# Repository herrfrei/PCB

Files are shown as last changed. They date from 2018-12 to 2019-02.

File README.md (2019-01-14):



Dieses Werk ist lizenziert unter einer [Creative Commons Namensnennung - Nicht-kommerziell - Weitergabe unter gleichen Bedingungen 4.0 International Lizenz](http://creativecommons.org/licenses/by-nc-sa/4.0/).

Bei Nutzung der Platinen freue ich mich über Feedback und kleine Aufmerksamkeiten aus meiner [Amazon Wunschliste](https://www.amazon.de/gp/registry/wishlist/3NNUQIQO20AAP/ref=nav_wishlist_lists_1).

# PCB
## HB-RF-USB
Eine Platine um die Homematic Funkmodule HM-MOD-RPI-PCB und RF-RPI-MOD per USB anschließen zu können.
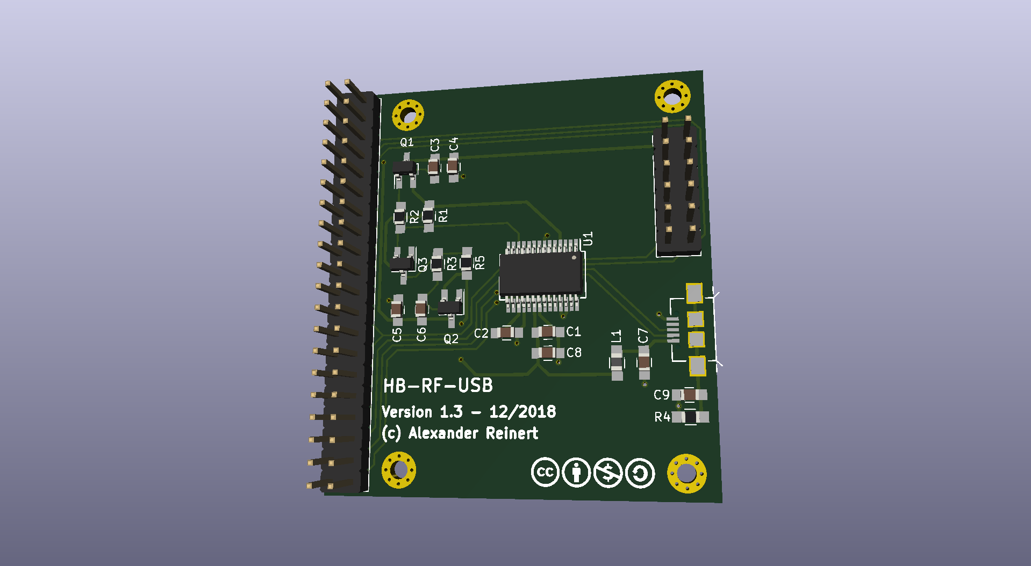
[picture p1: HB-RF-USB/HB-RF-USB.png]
Layout

[Schaltplan](HB-RF-USB/HB-RF-USB.pdf)

### Benötigte Bauteile:
* 1x FTDI FT232RL (U1)
* 1x Micro USB Connector MK5P
* 1x Kerko 4.7nF 0805 (C9)
* 1x Kerko 10nF 0805 (C7)
* 6x Kerko 100nF 0805 (C1-C6)
* 1x Kerko 4.7uF 0805 (C8)
* 2x Widerstand 1K 0805 (R2, R3)
* 2x Widerstand 10K 0805 (R1, R5)
* 1x Widerstand 1M 0805 (R4)
* 1x Ferritperle 30 Ohm 0805 (L1)
* 2x IRLML6402 (Q1, Q2)
* 1x IRLML2502 (Q1)
* 1x Pinheader 2*6
* 1x Pinheader 2*20

### EEPROM flashen
Das EEPROM des FT232RL muss mit dem Programm [FT_Prog](https://www.ftdichip.com/Support/Utilities.htm#FT_PROG) programmiert werden. Ein passendes Template findet sich [hier](HB-RF-USB/FT232R_Template.xml).
Die Platine benötigt spezielle Treiber, diese sind in [piVCCU3](https://github.com/alexreinert/piVCCU) ab Version 3.41.11-13 eingebaut.

## HB-UNI-SEN-BATT
Eine universelle Platine für Homebrew Geräte basierend auf [AskSin++ Library](https://github.com/pa-pa/AskSinPP)
Layout
[Schaltplan](HB-UNI-SEN-BATT/HB-UNI-SEN-BATT.pdf)

### Benötigte Bauteile:
* Arduino Pro Mini 3.3V 8Mhz (The Simple)
* CC1101 Modulplatine 868MHz
* 2x LEDs 3mm Low Current (Pin 4 und 5)
* 2x 470Ohm Widerstände (Vorwiderstand für LEDs)
* Elko 10uF 1,5mm
* 2x Goobay Batteriehalter Mignon Print
* Mikroschalter 6*6mm
* Stiftleiste RM 2mm 1x8 Pin (Für CC1101)
* Stiftleiste RM 2,54MM (nach Bedarf)
* IRLU024N (optional für Verpolungsschutz)
* 100KOhm Widerstand (optional für Verpolungsschutz)
* 2x 10KOhm Widerstand (optional Pullup für I2C)

### Passendes Gehäuse
* Camdenboss CBRS01SWH und CBRS01VWH

### Hinweise
* Achtung: Kein Überspannungschutz vorhanden
* Der Verpolungsschutz ist optional. Dafür Bauteil Q1 (IRLU024N) und R3 (100KOhm Widerstand) bestücken. Alternativ J8 auf der Platinenrückseite brücken um ohne Verpolungsschutz zu arbeiten.

## HB-UNI-SEN-PCB
Eine universelle Platine für Homebrew Geräte basierend auf [AskSin++ Library](https://github.com/pa-pa/AskSinPP)
Layout
[Schaltplan](HB-UNI-SEN-PCB/HB-UNI-SEN-PCB.pdf)

### Benötigte Bauteile:
* Arduino Pro Mini 3.3V 8Mhz (The Simple)
* CC1101 Modulplatine 868MHz
* 1x LEDs 3mm Low Current (Pin 4)
* 1x 470Ohm Widerstände (Vorwiderstand für LEDs)
* Mikroschalter 6*6mm
* Stiftleiste RM 2mm 1x8 Pin (Für CC1101)
* Stiftleiste RM 2,54MM (nach Bedarf)
* Optional: 2x 10KOhm Widerstand und 2x 10KOhm PTC (Temperaturmessung mit PTC an A0 und A1)

### Hinweise
* Achtung: kein Verpolungs- oder Überspannungschutz vorhanden
* Am I2C sind keine Pullups vorhanden, da diese im Regelfall auf I2C Platinen bereits integriert sind
* Aktuell fehlt noch ein Kondensator am VCC vom CC1101.

## HB-UNI-644 (Rev. 2)
Eine universelle Platine für Homebrew Geräte basierend auf [AskSin++ Library](https://github.com/pa-pa/AskSinPP) und dem ATmega644PA
Layout
[Schaltplan](HB-UNI-644/HB-UNI-644.pdf)

### Benötigte Bauteile:
#### Grundfunktion
* ATmega644PA oder ATmega1284P (TQFP44) (U1)
* CC1101 Modulplatine 868MHz ggf. mit RM 2.0 Pinheader (U2)
* 1x Kerko 10uF 0805 (C13)
* 7x Kerko 10nF 0805 (C1-C6, C14)
* 2x Widerstand 330 Ohm 0805 (R2, R3)
* 1x Widerstand 10K Ohm 0805 (R1)
* 1x Triple Color LED Common Cathode THT (D1)
* 1x Tactile Switch 2 Pin 6x3.5 SMD (SW1)
* 1x Quarz 8 Mhz HC49 THT (Y1) (optional)
* 2x Kerko 22pF 0805 (C7, C8) (optional für Quarz)
* Pinheader nach Bedarf

#### Power Option 1: Batteriebetrieb mit Step-Up
* 2x Goobay Batteriehalter Mignon Print
* 1x Widerstand 470K Ohm 0805 (R5)
* 1x Widerstand 100K Ohm 0805 (R6)
* 1x MAX1724EZK33 (U3)
* 1x LQH43CN100K03L (L1)
* 1x Kerko 10uF 0805 (C9)
* 1x Kerko 33uF 1206 (C10)
##### Verpolungsschutz und Überlastschutz
* 1x IRLML6244 (Q1)
* 1x Widerstand 100K Ohm 0805 (R4)
* 1x PTC 6V/250mA 1206 (F1)

#### Power Option 2: Externe Stromversorgung mit 5-9V, 100mA
* 1x HT-7533-1 (U4)
* 1x Kerko 10uF 50V 1206 (C11)
* 1x Kerko 10uF 0805 (C12)
* 1x Elko 1000uF 8mm*12mm (C15)
##### Verpolungsschutz und Überlastschutz
* 1x IRLML5203 (Q2)
* 1x Widerstand 100K Ohm 0805 (R11)
* 1x PTC 16V/250mA 1206 (F1)

#### Power Option 3: Externe Stromversorgung 5-24V, 1A
* 1x [MP2315 Power Module](https://de.aliexpress.com/item/DC-DC-R-cktritt-Abw-rtswandler-Einstellbar-4-5-V-24-V-zu-5-V-3A/32833398745.html)
   Kontakt zum Trimmer durchtrennen, Lötbrücke bei 3.3V anbringen
* 1x Elko 1000uF 8mm*12mm (C15)
##### Verpolungsschutz und Überlastschutz
* 1x IRF4905S (Q3)
* 1x Widerstand 100K Ohm 0805 (R12)
* 1x Zener 16V MiniMelf (D2)
* 1x PTC 30V/2A 1206 (F1)

#### I2C Pullup Widerstände (optional)
* 2x Widerstand 10k Ohm 0805 (R7, R8)

#### Vorwiderstände für NTC Messung an A0 und A1
* 2x Widerstand 10k Ohm 0805 (R9, R10)

### Passendes Gehäuse
* Camdenboss CBRS01SWH und CBRS01VWH

### Betrieb mit 5V, 16MHz bei Netzbetrieb
* Der MC kann auch mit 5V und dann mit 16MHz betrieben werden, dafür müssen ggü. oben folgende Anpassungen gemacht werden:
* Nicht möglich bei Power Option 1
* Bei Power Option 2: HT-7550-1 statt HT-7533-1 uf U4, Eingangsspannung >= 6V
* Bei Power Option 3: Lötbrücke auf MP2315 Modul bei 5V statt bei 3.3V, Eingangsspannung >= 6V
* CC1101 auf Position U5 statt auf U2
* Nicht bestücken: C13, C14
* Quarz Y1 mit 16MHz statt 8MHz
* Zusätzliche Bauteile
   * 1x LM-3480-3.3 (U6)
   * 1x TXS0108EPWR (U7)
   * 3x Kerko 10uF 0805 (C16, C18, C19)
   * 3x Kerko 10nF 0805 (C17, C20, C21)
* ACHTUNG: Alle VCC Pins laufen dann auf 5V, auch z.B. die vom I2C

### Hinweise
* Auch wenn die meisten Bauteile SMD sind, so ist die Platine für Handlötung entwickelt. Dementsprechend sind alle Teile mind. 0805 mit vergrößerten Pads für Handlötung.
* Es darf immer nur eine Power Option genutzt und bestückt werden
* Die rechte Seite der Platine kann entfernt werden, wenn die Batteriehalter oder das MP2315 Power Module nicht benötigt werden, es laufen keine Leiterbahnen rechts der Fräsung (abgesehen von denen für die Batterie bzw. Power Module)
* Die Lötbrücke J2 muss immer geschlossen werden, außer es wird der Verpolungsschutz für Batteriebetrieb verwendet
* Falls eine externe Spannung von 3.3V ohne Spannungsanpassung, Verpolungsschutz und Überlastschutz verwendet werden soll, dann muss die Lötbrücke J4 geschlossen werden
* Die Anschlüsse an J9 sind zusammen mit J12 genau passend für die Platine CJMCU-2803 um an den Anschlüssen ein Darlington Array zu verwenden (Jeder der Ports ist dann mit 500mA belastbar)
* Beschriftung der Anschlüsse folgt dem Bobuino Pinout

## HB-UNI-SEN-WEA
Eine passende Platine für den [Wettersensor von Jérôme](https://github.com/jp112sdl/HB-UNI-Sen-WEA/)
Layout
[Schaltplan](HB-UNI-SEN-WEA/HB-UNI-SEN-WEA.pdf)

### Benötigte Bauteile:
* Arduino Pro Mini 3.3V 8Mhz (The Simple)
* CC1101 Modulplatine 868MHz
* Elko 10uF 1,5mm
* Mikroschalter 6*6mm
* Kerko 1nf RM 2.5mm
* 10K Widerstand
* 100K Widerstand
* MPSA13 TO-92
* 4x Molex Spox 2-pol (Alternativ Stiftleiste oder Kabel direkt anlöten)
* 4x Molex Spox 4-pol (Alternativ Stiftleiste oder Kabel direkt anlöten)
* 1x Molex Spox 7-pol (Alternativ Stiftleiste oder Kabel direkt anlöten)
* Stiftleiste RM 2mm 1x8 Pin (Für CC1101)

### Hinweise
* Achtung: kein Verpolungs- oder Überspannungschutz vorhanden
* Am I2C sind keine Pullups vorhanden, da diese im Regelfall auf I2C Platinen bereits integriert sind

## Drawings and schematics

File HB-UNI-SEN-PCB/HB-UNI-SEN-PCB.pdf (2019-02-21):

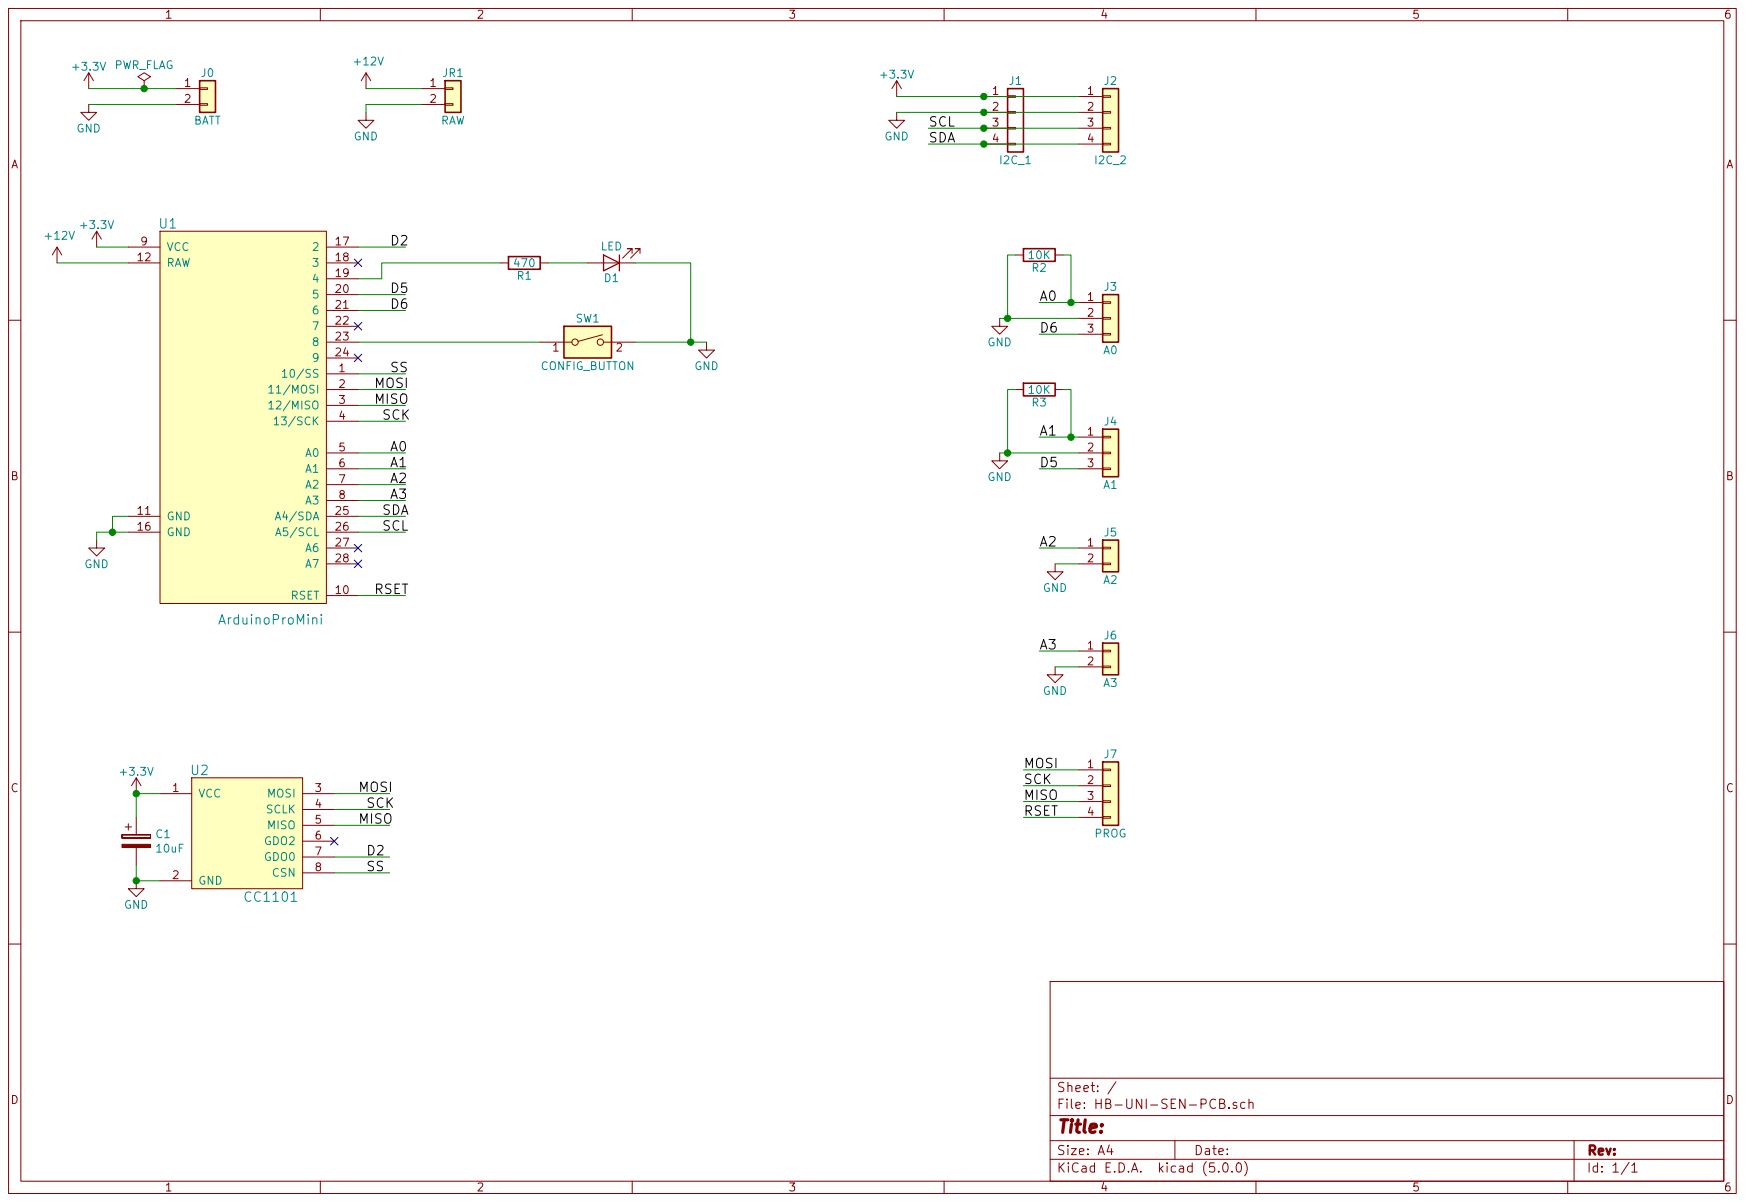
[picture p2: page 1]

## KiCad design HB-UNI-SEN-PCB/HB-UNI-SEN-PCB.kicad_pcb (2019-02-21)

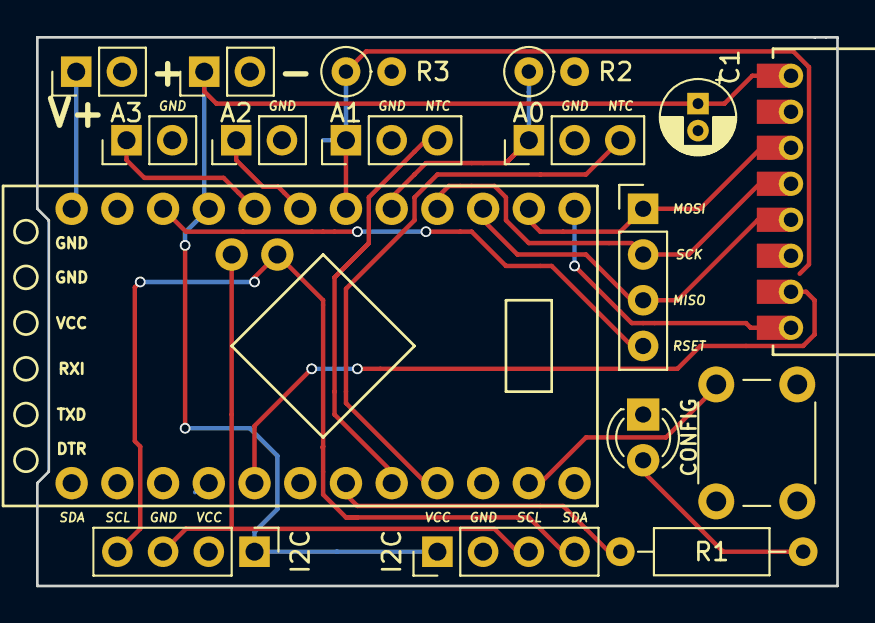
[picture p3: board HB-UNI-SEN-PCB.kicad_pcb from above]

Board: 2 copper layers, 44.4 x 30.5 mm, 17 parts (0 on the bottom side), 20 nets.

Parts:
C1: 10uF; CP_Radial_D4.0mm_P1.50mm
D1: LED; LED_D3.0mm
J0: BATT; Pin_Header_Straight_1x02_Pitch2.54mm
J1: I2C_1; Pin_Header_Straight_1x04_Pitch2.54mm
J2: I2C_2; Pin_Header_Straight_1x04_Pitch2.54mm
J3: A0; Pin_Header_Straight_1x03_Pitch2.54mm
J4: A1; Pin_Header_Straight_1x03_Pitch2.54mm
J5: A2; Pin_Header_Straight_1x02_Pitch2.54mm
J6: A3; Pin_Header_Straight_1x02_Pitch2.54mm
J7: PROG; Pin_Header_Straight_1x04_Pitch2.54mm
JR1: RAW; PinHeader_1x02_P2.54mm_Vertical
R1: 470; R_Axial_DIN0207_L6.3mm_D2.5mm_P10.16mm_Horizontal
R2, R3: 10K; R_Axial_DIN0207_L6.3mm_D2.5mm_P2.54mm_Vertical
SW1: CONFIG_BUTTON; SW_PUSH_6mm_h5mm
U1: ArduinoProMini
U2: CC1101

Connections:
+3V3: C1.1, J0.1, J1.1, J2.1, U1.9, U2.1
+12V: JR1.1, U1.12
/A0: J3.1, R2.1, U1.5
/A1: J4.1, R3.1, U1.6
/A2: J5.1, U1.7
/A3: J6.1, U1.8
/D2: U1.17, U2.7
/D5: J4.3, U1.20
/D6: J3.3, U1.21
/MISO: J7.3, U1.3, U2.5
/MOSI: J7.1, U1.2, U2.3
/RSET: J7.4, U1.10
/SCK: J7.2, U1.4, U2.4
/SCL: J1.3, J2.3, U1.26
/SDA: J1.4, J2.4, U1.25
/SS: U1.1, U2.8
GND: C1.2, D1.1, J0.2, J1.2, J2.2, J3.2, J4.2, J5.2, J6.2, JR1.2, R2.2, R3.2, SW1.2, U1.11, U1.16, U2.2
unnamed: D1.2, R1.1
unnamed: R1.2, U1.19
unnamed: SW1.1, U1.23

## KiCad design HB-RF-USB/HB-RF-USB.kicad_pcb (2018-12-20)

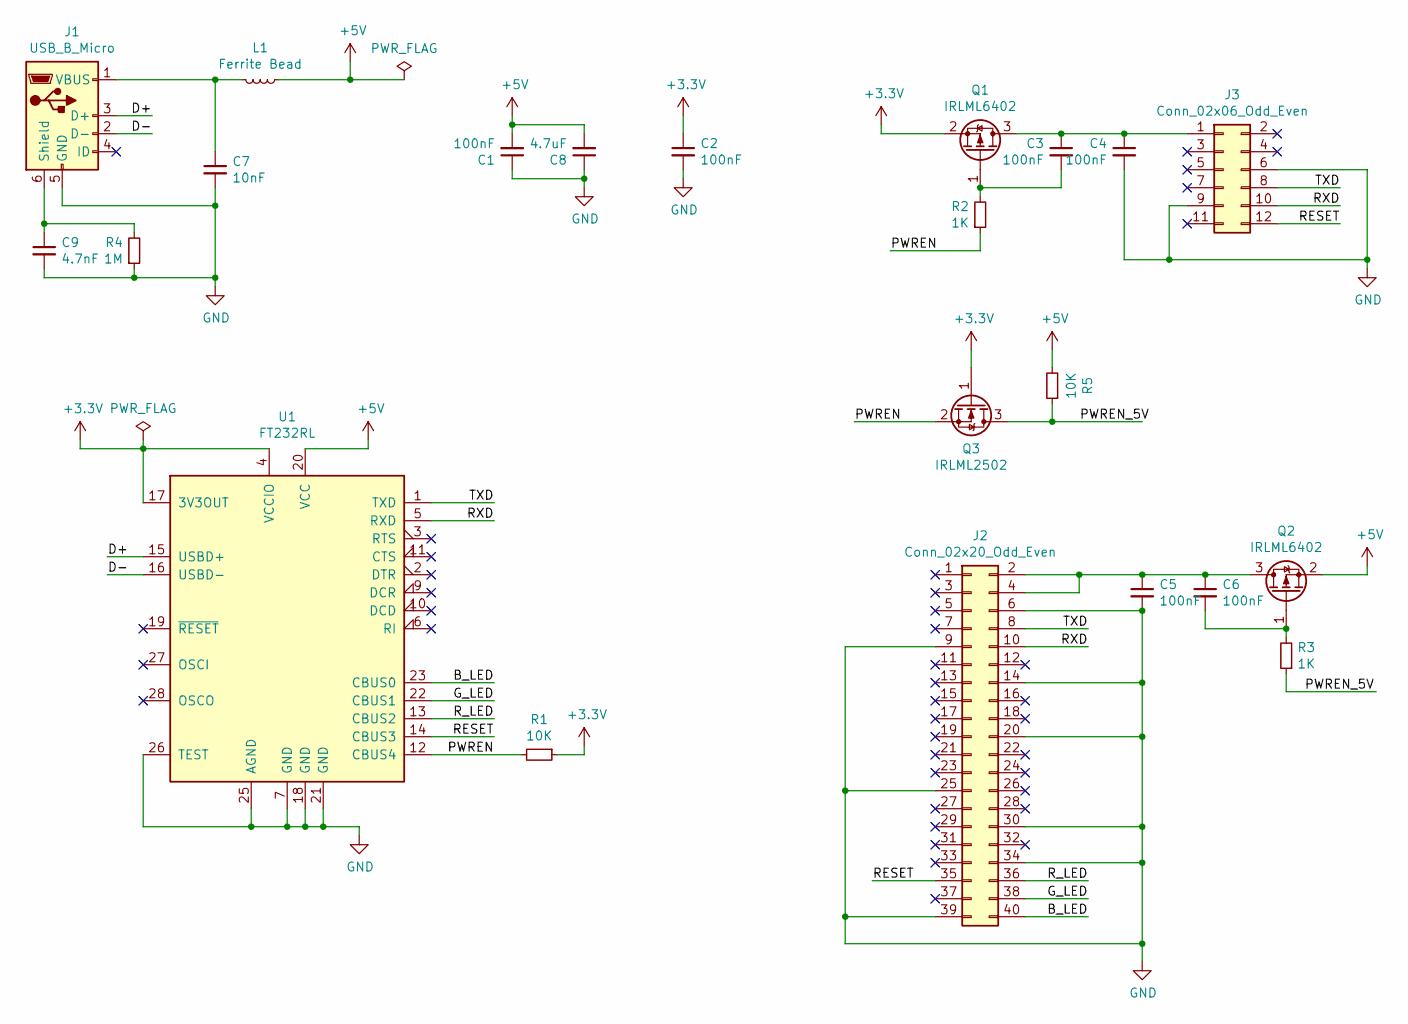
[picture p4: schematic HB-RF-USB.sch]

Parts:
C1, C2, C3, C4, C5, C6: 100nF; C_0805_HandSoldering
C7: 10nF; C_0805_HandSoldering
C8: 4.7uF; C_0805_HandSoldering
C9: 4.7nF; C_0805_HandSoldering
J1: USB_B_Micro; USB-MICRO-MK5P
J2: Conn_02x20_Odd_Even; Pin_Header_Straight_2x20_Pitch2.54mm
J3: Conn_02x06_Odd_Even; Pin_Header_Straight_2x06_Pitch2.54mm
L1: Ferrite Bead; L_0805_HandSoldering
Q1, Q2: IRLML6402; SOT-23_Handsoldering
Q3: IRLML2502; SOT-23_Handsoldering
R1, R5: 10K; R_0805_HandSoldering
R2, R3: 1K; R_0805_HandSoldering
R4: 1M; R_0805_HandSoldering
U1: FT232RL; SSOP-28_5.3x10.2mm_Pitch0.65mm

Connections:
+3V3: C2.1, Q1.2 (S), Q3.1 (G), R1.1, U1.4 (VCCIO), U1.17 (3V3OUT)
+5V: C1.2, C8.2, L1.1, Q2.2 (S), R5.2, U1.20 (VCC)
/B_LED: J2.40, U1.23 (CBUS0)
/D+: J1.3 (D+), U1.15 (USBD+)
/D-: J1.2 (D-), U1.16 (USBD-)
/G_LED: J2.38, U1.22 (CBUS1)
/PWREN: Q3.2 (S), R1.2, R2.1, U1.12 (CBUS4)
/PWREN_5V: Q3.3 (D), R3.1, R5.1
/RESET: J2.35, J3.12, U1.14 (CBUS3)
/RXD: J2.10, J3.10, U1.5 (RXD)
/R_LED: J2.36, U1.13 (CBUS2)
/TXD: J2.8, J3.8, U1.1 (TXD)
GND: C1.1, C2.2, C4.2, C5.2, C7.2, C8.1, C9.2, J1.5 (GND), J2.6, J2.9, J2.14, J2.20, J2.25, J2.30, J2.34, J2.39, J3.6, J3.9, R4.1, U1.7 (GND), U1.18 (GND), U1.21 (GND), U1.25 (AGND), U1.26 (TEST)
unnamed: C3.1, C4.1, J3.1, Q1.3 (D)
unnamed: C3.2, Q1.1 (G), R2.2
unnamed: C5.1, C6.1, J2.2, J2.4, Q2.3 (D)
unnamed: C6.2, Q2.1 (G), R3.2
unnamed: C7.1, J1.1 (VBUS), L1.2
unnamed: C9.1, J1.6 (Shield), R4.2

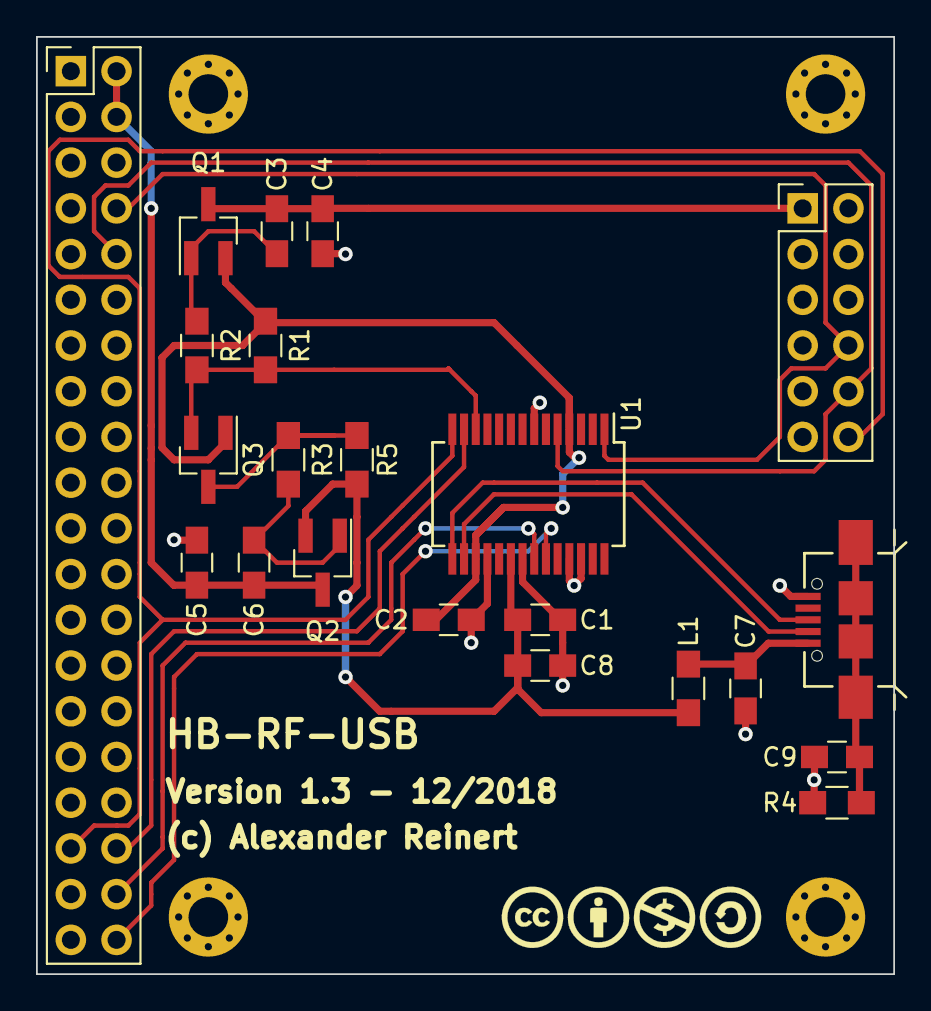
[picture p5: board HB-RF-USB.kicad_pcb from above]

Board: 2 copper layers, 47.6 x 52.1 mm, 22 parts (0 on the bottom side), 19 nets.

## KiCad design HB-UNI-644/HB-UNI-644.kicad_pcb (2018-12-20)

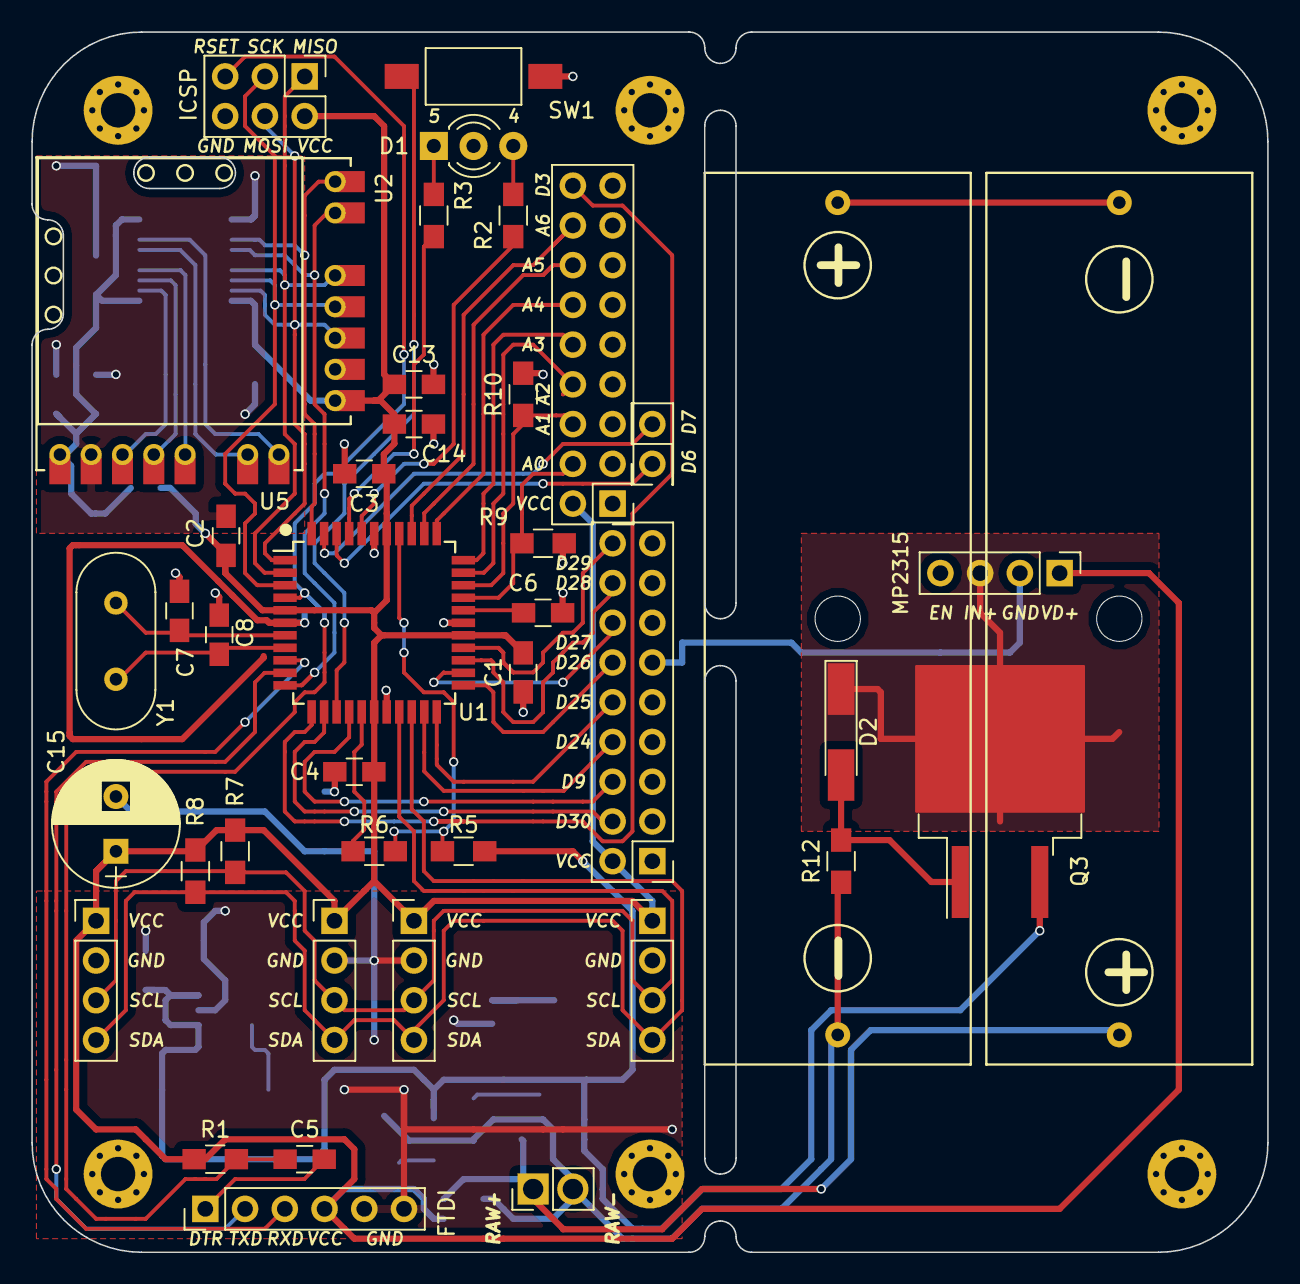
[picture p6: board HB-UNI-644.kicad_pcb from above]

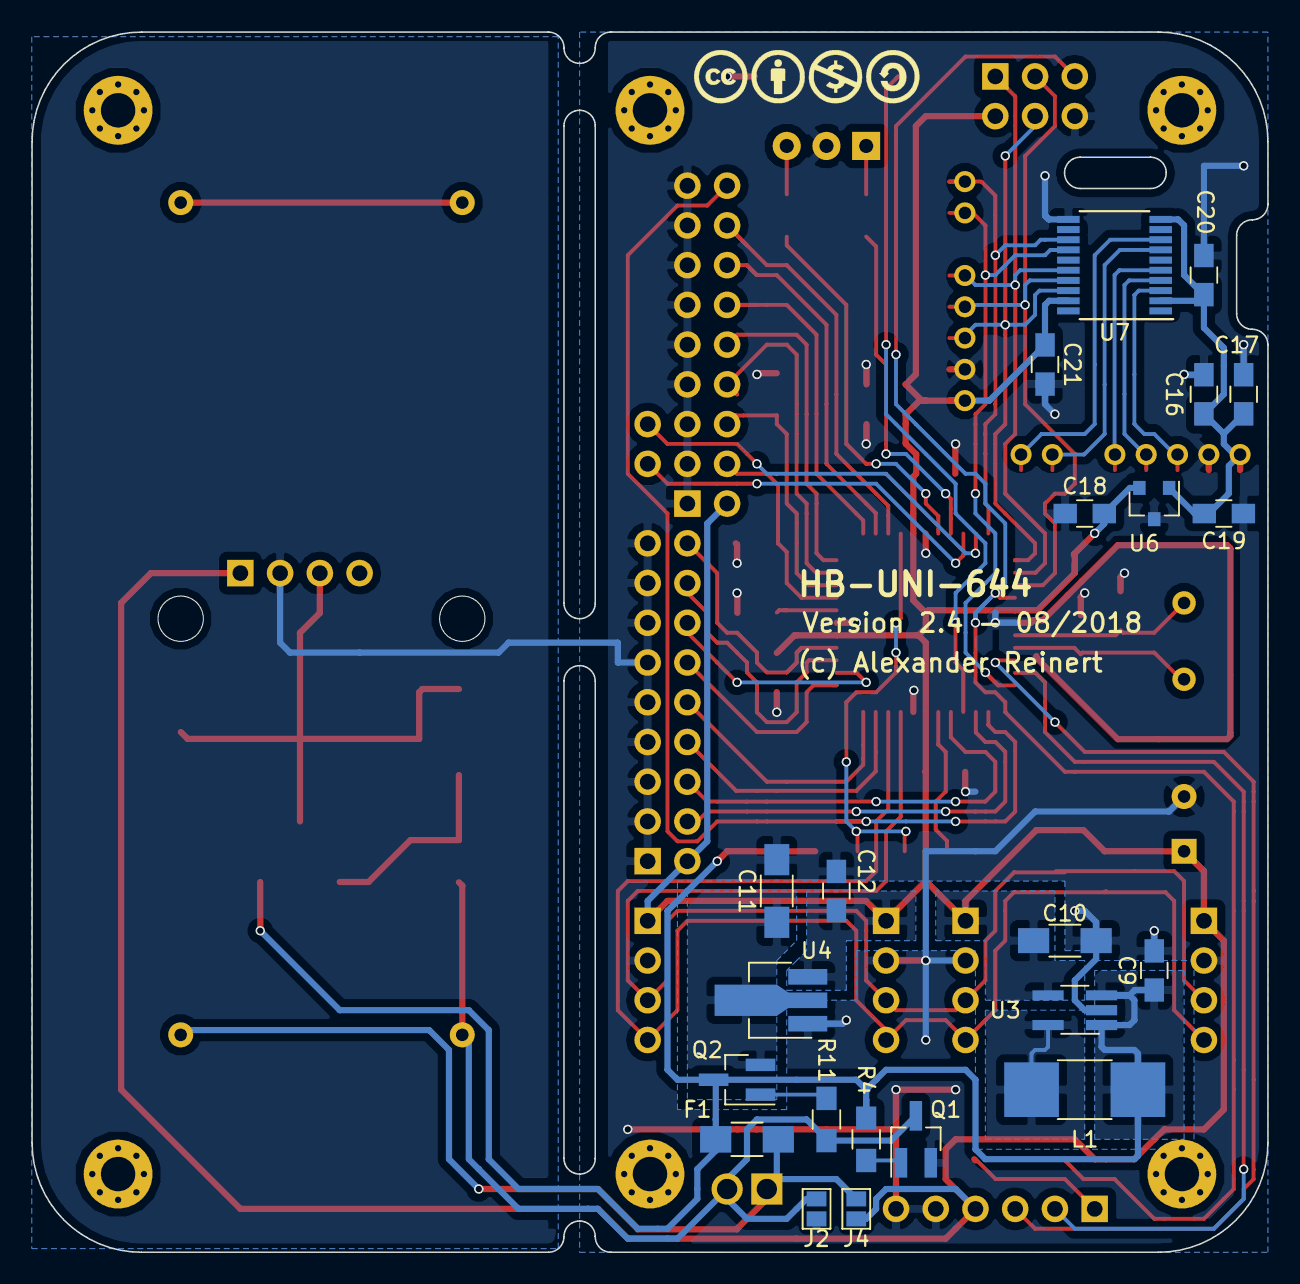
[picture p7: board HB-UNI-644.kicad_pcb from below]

Board: 2 copper layers, 79.0 x 78.0 mm, 64 parts (22 on the bottom side), 57 nets.

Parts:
BT1, BT2: AA; BATTERY_HOLDER_GOOBAY_AA
C1, C2, C3, C4, C5, C6, C14, C17, C20, C21: 10nF; C_0805_HandSoldering
C7, C8: 22pF; C_0805_HandSoldering
C9, C12, C13, C16, C18, C19: 10uF; C_0805_HandSoldering
C10: 33uF; C_1206_HandSoldering
C11: 10uF 50V; C_1206_HandSoldering
C15: 1000uF; CP_Radial_D8.0mm_P3.50mm
D1: LED_Dual; LED_D3.0mm-3
D2: ZMM16; D_MiniMELF_Handsoldering
F1: *; R_1206_HandSoldering
J1: FTDI; Pin_Header_Straight_1x06_Pitch2.54mm
J2, J4: GS2
J3: I2C_1; Pin_Header_Straight_1x04_Pitch2.54mm
J5: I2C_2; Pin_Header_Straight_1x04_Pitch2.54mm
J6: I2C_3; Pin_Header_Straight_1x04_Pitch2.54mm
J7: I2C_4; Pin_Header_Straight_1x04_Pitch2.54mm
J8: Conn_A; Pin_Header_Straight_2x09_Pitch2.54mm
J9: Conn_B; Pin_Header_Straight_2x09_Pitch2.54mm
J10: ICSP; Pin_Header_Straight_2x03_Pitch2.54mm
J11: RAW; Pin_Header_Straight_1x02_Pitch2.54mm
J12: Conn_01x04; Pin_Header_Straight_1x04_Pitch2.54mm
J13: Conn_NTC; Pin_Header_Straight_2x01_Pitch2.54mm
L1: LQH43CN100K03L; L_1812_HandSoldering
Q1: IRLML6244; SOT-23_Handsoldering
Q2: IRLML5203; SOT-23_Handsoldering
Q3: IRF4905S; TO-263-2
R1, R7, R8, R9, R10: 10K; R_0805_HandSoldering
R2, R3: 330; R_0805_HandSoldering
R4, R6, R11, R12: 100K; R_0805_HandSoldering
R5: 470K; R_0805_HandSoldering
SW1: CONFIG; SW_SPST_FSMSM
U1: ATMEGA644PA-AU; TQFP-44_10x10mm_Pitch0.8mm
U2, U5: CC1101
U3: MAX1724; TSOT-23-5_HandSoldering
U4: HT7533-1; SOT-89-3_Handsoldering
U6: LM3480-3.3; SOT-23
U7: TXS0108EPWR; TSSOP-20_4.4x6.5mm_Pitch0.65mm
Y1: 8MHz/16MHz; Crystal_HC49-U_Vertical

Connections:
+3V3: C16.2, C17.2, C19.2, C20.2, U5.1, U6.1, U7.2, U7.10
/A0: J8.4, R9.2, U1.30
/A1: J8.6, R10.2, U1.31
/A2: J8.8, U1.32
/A3: J8.10, U1.33
/A4: J8.12, U1.34
/A5: J8.14, U1.35
/A6: J8.16, U1.36
/A7: R5.1, R6.2, U1.37
/D2: U1.11, U2.7, U7.14
/D3: J8.18, U1.12
/D4: R2.2, U1.40
/D5: R3.2, U1.41
/D6: J13.1, U1.42
/D7: J13.2, U1.43
/D8: SW1.1, U1.14
/D9: J9.6, U1.15
/D24: J9.8, U1.21
/D25: J9.10, U1.22
/D26: J9.12, U1.23
/D27: J9.14, U1.24
/D28: J9.16, U1.25
/D29: J9.18, U1.26
/D30: J9.4, U1.13
/D31: R6.1, U1.16
/DTR: C5.1, J1.1
/MISO: J10.1, U1.2, U2.5, U7.16
/MOSI: J10.4, U1.1, U2.3, U7.18
/RAW+: BT1.1, F1.2, J4.2, J11.1
/RAW+FUSE: C9.1, F1.1, L1.1, Q2.3, Q3.3, R4.2, R5.2, U3.1, U3.3
/RAW-: BT2.2, J2.2, J11.2, Q1.3, R11.2, R12.2
/RSET: C5.2, J10.5, R1.2, U1.4
/RXD: J1.3, U1.9
/SCK: J10.3, U1.3, U2.4, U7.17
/SCL: J3.3, J5.3, J6.3, J7.3, R7.2, U1.19
/SDA: J3.4, J5.4, J6.4, J7.4, R8.2, U1.20
/SS: U1.44, U2.8, U7.13
/TXD: J1.2, U1.10
GND: C1.1, C2.1, C3.1, C4.1, C6.2, C7.1, C8.2, C9.2, C10.2, C11.2, C12.2, C13.1, C14.1, C15.2, C16.1, C17.1, C18.1, C19.1, C20.1, C21.2, D1.2, J1.5, J1.6, J2.1, J3.2, J5.2, J6.2, J7.2, J8.1, J8.3, J8.5, J8.7, J8.9, J8.11, J8.13, J8.15, J8.17, J9.1, J9.3, J9.5, J9.7, J9.9, J9.11, J9.13, J9.15, J9.17, J10.6, J12.2, Q1.2, R9.1, R10.1, SW1.2, U1.6, U1.18, U1.28, U1.39, U2.2, U3.2, U4.1, U5.2, U6.3, U7.11
unnamed: BT1.2, BT2.1
unnamed: C6.1, U1.29
unnamed: C7.2, U1.7, Y1.1
unnamed: C8.1, U1.8, Y1.2
unnamed: C11.1, Q2.2, U4.2
unnamed: D1.1, R3.1
unnamed: D1.3, R2.1
unnamed: D2.1, J12.3, Q3.2
unnamed: D2.2, Q3.1, R12.1
unnamed: L1.2, U3.5
unnamed: Q1.1, R4.1
unnamed: Q2.1, R11.1
unnamed: U5.3, U7.3
unnamed: U5.4, U7.4
unnamed: U5.5, U7.5
unnamed: U5.7, U7.7
unnamed: U5.8, U7.8
VCC: C1.2, C2.2, C3.2, C4.2, C10.1, C12.1, C13.2, C14.2, C15.1, C18.2, C21.1, J1.4, J3.1, J4.1, J5.1, J6.1, J7.1, J8.2, J9.2, J10.2, J12.1, R1.1, R7.1, R8.1, U1.5, U1.17, U1.27, U1.38, U2.1, U3.4, U4.3, U6.2, U7.19

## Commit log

2018-12-20 Added HB-RF-USB
    [HB-RF-USB-B.Cu.gbr, HB-RF-USB-B.Mask.gbr, HB-RF-USB-B.SilkS.gbr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]
2019-02-21 Updated to v1.5: - Added raw power input - Moved two resistors and some jumpers - Rerouted some tracks
    [HB-UNI-SEN-PCB.kicad_pcb, HB-UNI-SEN-PCB.sch]
2019-02-21 Added missing capacitor at CC1101
    [HB-UNI-SEN-PCB.kicad_pcb, HB-UNI-SEN-PCB.sch]

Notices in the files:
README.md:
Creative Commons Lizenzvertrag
